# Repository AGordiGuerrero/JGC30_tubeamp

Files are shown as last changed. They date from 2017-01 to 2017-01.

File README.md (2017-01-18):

# JGC30_tubeamp

"Small" guitar tube amplifier with two preamp channels.

It is conceived to be inserted in a small combo box with a single 12" speaker. 

Author: @AGordiGuerrero
        @SolEpcc
        University of Extremadura. Spain.
        
Features:
 - Two preamp channels:
      - Channel 1: Vox AC30 Top Boost type
      - Channel 2: Marshall JCM800 type
  - Around 10-15W of output power

Revision history:
  - V0.3: preamp PCB design with Kicad. It includes a supposedly well defined BOM.

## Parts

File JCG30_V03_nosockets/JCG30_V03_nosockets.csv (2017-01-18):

Reference | Value | Footprint | Datasheet | Characteristics | Description | MFN | MFP | Package ID | Source1 | Source1Part | Source1Price | Source1Link | Notes | MFS
P1 | INPUT | Wire_Pads:SolderWirePad_single_1-5mmDrill
P19 | OUTPUT | Wire_Pads:SolderWirePad_single_1-5mmDrill
U2 | CH1/CH2_A | Socket_Strips:Socket_Strip_Straight_1x03 |  | 120VAC | 3PDT toggle switch, ON - NONE - ON | E-Switch | 1003P1T1B1M1QEH | Value | Mouser | 612-100-M1111 | 4,79 € | http://www.mouser.es/ProductDetail/E-Switch/1003P1T1B1M1QEH/ | Value
R1 | 1M | Resistors_THT:Resistor_Horizontal_RM10mm |  | 0.25W | Metal film through hole resistor | Vishay | CCF551M00FKE36 | MFR | Mouser | 71-CCF551M00FKE36 | 0.16€ | http://www.mouser.es/ProductDetail/Vishay/CCF551M00FKE36/ | Value | Value
C17 | 47u | Capacitors_THT:C_Radial_D14_L31.5_P5 |  | 450VDC | General Purpose Electrolytic Capacitors | Panasonic | EEU-EE2W470S | EE | Mouser | 667-EEU-EE2W470S | 2.32€ | http://www.mouser.es/ProductDetail/Panasonic/EEU-EE2W470S/?qs=sGAEpiMZZMtZ1n0r9vR22dN7zJS18SGVwev2rCc7kfs%3d | Value
R4 | 2k7 | Resistors_THT:Resistor_Horizontal_RM10mm |  | 0.25W | Metal film through hole resistor | Yageo | MFR-25FRF52-2K7 | MFR | Mouser | 603-MFR-25FRF52-2K7 | 0.113€ | http://www.mouser.es/ProductDetail/Yageo/MFR-25FRF52-2K7/ | Value
RV1 | 1MA | Potentiometers:Potentiometer_WirePads_Small |  | 60mW | Carbon potentiometer, rotatory, serrated | Alpha (Taiwan) | RV16AF-20-15K-A1M-3LA | Through hole, panel mount | Mouser | 313-1530F-1M | 1,62 € | http://www.mouser.es/ProductDetail/Alpha-Taiwan/RV16AF-20-15K-A1M-3LA/ | Value
R2 | 68k | Resistors_THT:Resistor_Horizontal_RM10mm |  | 0.25W | Metal film through hole resistor | Yageo | MFR-25FTE52-68K | MFR | Mouser | 603-MFR-25FTE52-68K | 0.113€ | http://www.mouser.es/ProductDetail/Yageo/MFR-25FTE52-68K/?qs=sGAEpiMZZMu61qfTUdNhG0IXHLFuiNndqkYkeLIi2jk%3d | Value
C2 | 680n | Capacitors_THT:C_Rect_L7_W4.5_P5 |  | 50 VDC | Metallized Polyester (PET) Capacitors PCM 5 mm | WIMA | MKS2B036801C00JA00 | MKS2 | Mouser | 505-MKS2B036801C00JA | 0.342€ | http://www.mouser.es/ProductDetail/WIMA/MKS2B036801C00JA00/?qs=sGAEpiMZZMv1cc3ydrPrF7l45uRd9dVhXD8p2Cb2qBg%3d | Value
U1 | BRIGHT | Socket_Strips:Socket_Strip_Straight_1x02 |  | 125VAC | Toggle switch, ON-OFF | Mountain Switch | 10TC605 | Bulk | Mouser | 10TC605 | 2.16 € | http://www.mouser.es/ProductDetail/Mountain-Switch/10TC605/ | Value
C9 | 22n | Capacitors_THT:C_Rect_L7_W3.5_P5 |  | 400VAC | Double Metallized Polypropylene Film | Kemet | PHE450MK5220JR05 | PHE450 | Mouser | 80-PHE450MK5220JR05 | 0.67€ | http://www.mouser.es/ProductDetail/Kemet/PHE450MK5220JR05/ | Value
C5 | 470p | Capacitors_THT:C_Rect_L10_W2.5_P7.5 |  | 400VAC | Metallized Polypropylene Film Capacitor DC and Pulse Applications | Kemet | R75QD0470DQ30J | R75 | Mouser | 80-R75QD0470DQ30J | 0.811€ | http://www.mouser.es/ProductDetail/Kemet/R75QD0470DQ30J/ | Value
R15 | 47k | Resistors_THT:Resistor_Horizontal_RM10mm |  | 0.5W, 700W | Metal film through hole resistor | KOA Speer | MF1/2DC4702F | MF | Mouser | 660-MF1/2DC4702F | 0.161€ | http://www.mouser.es/ProductDetail/KOA-Speer/MF1-2DC4702F/?qs=sGAEpiMZZMu61qfTUdNhG0RUkTLGOdTMbrAUdwu816A%3d | Value
U4 | CH1/CH2_B | Socket_Strips:Socket_Strip_Straight_1x02 |  | Value | Value | Value | Value | Value | Value | Value | Value | Value | Value
P2 | V2A_G | Wire_Pads:SolderWirePad_single_1-5mmDrill
P3 | V2A_K | Wire_Pads:SolderWirePad_single_1-5mmDrill
P4 | V2A_A | Wire_Pads:SolderWirePad_single_1-5mmDrill
P8 | V2B_G | Wire_Pads:SolderWirePad_single_1-5mmDrill
P9 | V2B_K | Wire_Pads:SolderWirePad_single_1-5mmDrill
P10 | V2B_A | Wire_Pads:SolderWirePad_single_1-5mmDrill
P5 | V1A_G | Wire_Pads:SolderWirePad_single_1-5mmDrill
P6 | V1A_K | Wire_Pads:SolderWirePad_single_1-5mmDrill
P7 | V1A_A | Wire_Pads:SolderWirePad_single_1-5mmDrill
P11 | V3A_G | Wire_Pads:SolderWirePad_single_1-5mmDrill
P12 | V3A_K | Wire_Pads:SolderWirePad_single_1-5mmDrill
P13 | V3A_A | Wire_Pads:SolderWirePad_single_1-5mmDrill
P14 | V3B_G | Wire_Pads:SolderWirePad_single_1-5mmDrill
P15 | V3B_K | Wire_Pads:SolderWirePad_single_1-5mmDrill
P16 | V3B_A | Wire_Pads:SolderWirePad_single_1-5mmDrill
P17 | VCC | Wire_Pads:SolderWirePad_single_1-5mmDrill
C3 | 22u | Capacitors_THT:C_Radial_D6.3_L11.2_P2.5 |  | 35VDC | Electrolitic Aluminium Radial Lead Type | Panasonic | ECA-1VM220B | M | Mouser | ECA-1VM220B | 0.16€ | http://www.mouser.es/ProductDetail/Panasonic/ECA-1VM220B/?qs=sGAEpiMZZMvwFf0viD3Y3ffldXPLozaytDH8DKgv7WI%3d | Value
P18 | GROUND | Wire_Pads:SolderWirePad_single_1-5mmDrill
R12 | 1M | Resistors_THT:Resistor_Horizontal_RM10mm |  | 0.25W | Metal film through hole resistor | Vishay | CCF551M00FKE36 | MFR | Mouser | 71-CCF551M00FKE36 | 0.16€ | http://www.mouser.es/ProductDetail/Vishay/CCF551M00FKE36/ | Value
R3 | 68k | Resistors_THT:Resistor_Horizontal_RM10mm |  | 0.25W | Metal film through hole resistor | Yageo | MFR-25FTE52-68K | MFR | Mouser | 603-MFR-25FTE52-68K | 0.113€ | http://www.mouser.es/ProductDetail/Yageo/MFR-25FTE52-68K/?qs=sGAEpiMZZMu61qfTUdNhG0IXHLFuiNndqkYkeLIi2jk%3d | Value
R5 | 100k | Resistors_THT:Resistor_Horizontal_RM10mm |  | 0.5W, 500V | Metal film through hole resistor | Vishay | CMF60100K00FKEB | CMFIndustrial | Mouser | 71-CMF60100K00FKEB | 0.556€ | http://www.mouser.es/ProductDetail/Vishay-Dale/CMF60100K00FKEB/ | Value
R6 | 820R | Resistors_THT:Resistor_Horizontal_RM10mm |  | 0.25W | Metal film through hole resistor | Yageo | MFR-25FBF52-820R | MFR | Mouser | 603-MFR-25FBF52-820R | 0.113€ | http://www.mouser.es/ProductDetail/Yageo/MFR-25FBF52-820R/ | Value
R13 | 820R | Resistors_THT:Resistor_Horizontal_RM10mm |  | 0.25W | Metal film through hole resistor | Yageo | MFR-25FBF52-820R | MFR | Mouser | 603-MFR-25FBF52-820R | 0.113€ | http://www.mouser.es/ProductDetail/Yageo/MFR-25FBF52-820R/ | Value
R10 | 100k | Resistors_THT:Resistor_Horizontal_RM10mm |  | 0.5W, 500V | Metal film through hole resistor | Vishay | CMF60100K00FKEB | CMFIndustrial | Mouser | 71-CMF60100K00FKEB | 0.556€ | http://www.mouser.es/ProductDetail/Vishay-Dale/CMF60100K00FKEB/ | Value
R16 | 100k | Resistors_THT:Resistor_Horizontal_RM10mm |  | 0.5W, 500V | Metal film through hole resistor | Vishay | CMF60100K00FKEB | CMFIndustrial | Mouser | 71-CMF60100K00FKEB | 0.556€ | http://www.mouser.es/ProductDetail/Vishay-Dale/CMF60100K00FKEB/ | Value
R7 | 220k | Resistors_THT:Resistor_Horizontal_RM10mm |  | 2W, 500V | Metal film through hole resistor | Yageo | FMP200JR-52-220K | FMP | Mouser | 603-FMP200JR-52-220K | 0.245€ | http://www.mouser.es/ProductDetail/Yageo/FMP200JR-52-220K/?qs=sGAEpiMZZMu61qfTUdNhGztMfEiwFKKT8tJfn5xrilY%3d | Value
R19 | 220k | Resistors_THT:Resistor_Horizontal_RM10mm |  | 2W, 500V | Metal film through hole resistor | Yageo | FMP200JR-52-220K | FMP | Mouser | 603-FMP200JR-52-220K | 0.245€ | http://www.mouser.es/ProductDetail/Yageo/FMP200JR-52-220K/?qs=sGAEpiMZZMu61qfTUdNhGztMfEiwFKKT8tJfn5xrilY%3d | Value
R14 | 47k | Resistors_THT:Resistor_Horizontal_RM10mm |  | 0.5W, 700W | Metal film through hole resistor | KOA Speer | MF1/2DC4702F | MF | Mouser | 660-MF1/2DC4702F | 0.161€ | http://www.mouser.es/ProductDetail/KOA-Speer/MF1-2DC4702F/?qs=sGAEpiMZZMu61qfTUdNhG0RUkTLGOdTMbrAUdwu816A%3d | Value
R8 | 470k | Resistors_THT:Resistor_Horizontal_RM10mm |  | 0.25W, 250V | Metal film through hole resistor | Yageo | MFR-25FRF52-470K | MFR | Mouser | 603-MFR-25FRF52-470K | 0.087€ | http://www.mouser.es/ProductDetail/Yageo/MFR-25FRF52-470K/?qs=sGAEpiMZZMu61qfTUdNhG0IXHLFuiNndCa9frJHvSy8%3d | Value
R11 | 470k | Resistors_THT:Resistor_Horizontal_RM10mm |  | 0.25W, 250V | Metal film through hole resistor | Yageo | MFR-25FRF52-470K | MFR | Mouser | 603-MFR-25FRF52-470K | 0.087€ | http://www.mouser.es/ProductDetail/Yageo/MFR-25FRF52-470K/?qs=sGAEpiMZZMu61qfTUdNhG0IXHLFuiNndCa9frJHvSy8%3d | Value
R17 | 33k | Resistors_THT:Resistor_Horizontal_RM10mm |  | 0.6W, 350V | Metal film through hole resistor | Yageo | 603-MF0207FTE52-33K | MF0 | Mouser | 603-MF0207FTE52-33K | 0.104€ | http://www.mouser.es/ProductDetail/Yageo/MF0207FTE52-33K/?qs=sGAEpiMZZMu61qfTUdNhG9FodMeJR7x9rJbMY0rijM4%3d | Value
R18 | 33R | Resistors_THT:Resistor_Horizontal_RM10mm |  | 2W, 500V | Metal film through hole resistor | Vishay | PR02000203309JR500 | 5073 | Mouser | 594-5083NW33R00J | 0.321€ | http://www.mouser.es/ProductDetail/Vishay-BC-Components/PR02000203309JR500/ | Value
R20 | 47R | Resistors_THT:Resistor_Horizontal_RM10mm |  | 2W, 500V | Metal film through hole resistor | Vishay | PR02000204709JR500 | 5073 | Mouser | 594-5083NW47R00J | 0.321€ | http://www.mouser.es/ProductDetail/Vishay-BC-Components/PR02000203309JR500/ | Value
R9 | 10k | Resistors_THT:Resistor_Horizontal_RM10mm |  | 0.25W | Metal film through hole resistor | Yageo | MFR-25FRF52-10K | MFR | Mouser | 603-MFR-25FRF52-10K | 0.094€ | http://www.mouser.es/ProductDetail/Yageo/MFR-25FRF52-10K/?qs=sGAEpiMZZMu61qfTUdNhGztMfEiwFKKTpKeEBKehEYg%3d | Value
C11 | 680n | Capacitors_THT:C_Rect_L7_W4.5_P5 |  | 50 VDC | Metallized Polyester (PET) Capacitors PCM 5 mm | WIMA | MKS2B036801C00JA00 | MKS2 | Mouser | 505-MKS2B036801C00JA | 0.342€ | http://www.mouser.es/ProductDetail/WIMA/MKS2B036801C00JA00/?qs=sGAEpiMZZMv1cc3ydrPrF7l45uRd9dVhXD8p2Cb2qBg%3d | Value
C8 | 22u | Capacitors_THT:C_Radial_D6.3_L11.2_P2.5 |  | 35VDC | Electrolitic Aluminium Radial Lead Type | Panasonic | ECA-1VM220B | M | Mouser | ECA-1VM220B | 0.16€ | http://www.mouser.es/ProductDetail/Panasonic/ECA-1VM220B/?qs=sGAEpiMZZMvwFf0viD3Y3ffldXPLozaytDH8DKgv7WI%3d | Value
C4 | 470p | Capacitors_THT:C_Rect_L7_W4.5_P5 |  | 63VAC | Metallized Polyester (PET) Capacitors PCM 5 mm | WIMA | FKP2D004701D00JSSD | FKP2 | Mouser | 505-FKP2470/100/5 | 0.352€ | http://www.mouser.es/ProductDetail/WIMA/FKP2D004701D00JSSD/ | Value
C10 | 470p | Capacitors_THT:C_Rect_L7_W4.5_P5 |  | 63VAC | Metallized Polyester (PET) Capacitors PCM 5 mm | WIMA | FKP2D004701D00JSSD | FKP2 | Mouser | 505-FKP2470/100/5 | 0.352€ | http://www.mouser.es/ProductDetail/WIMA/FKP2D004701D00JSSD/ | Value
C16 | 470p | Capacitors_THT:C_Rect_L10_W2.5_P7.5 |  | 400VAC | Metallized Polypropylene Film Capacitor DC and Pulse Applications | Kemet | R75QD0470DQ30J | R75 | Mouser | 80-R75QD0470DQ30J | 0.811€ | http://www.mouser.es/ProductDetail/Kemet/R75QD0470DQ30J/ | Value
C6 | 1n | Capacitors_THT:C_Rect_L7_W4.5_P5 |  | 63VAC | Polypropylene (PP) Capacitors | WIMA | FKS2D011001A00KC00 | FKP2 | Mouser | 505-FKS2D011001A00KC00 | 0.191€ | http://www.mouser.es/ProductDetail/WIMA/FKS2D011001A00KC00/?qs=sGAEpiMZZMv1cc3ydrPrF2CPLAojp4yWK6zCnEZkMTQ%3d | Value
C7 | 100p | Capacitors_THT:C_Rect_L7_W4.5_P5 |  | 63VAC | Polypropylene (PP) Capacitors | WIMA | FKS2D011001A00KC00 | FKP2 | Mouser | 505-FKP2D001001D00JO00 | 0.141€ | http://www.mouser.es/ProductDetail/WIMA/FKP2D001001D00JO00/?qs=sGAEpiMZZMv1cc3ydrPrF2CPLAojp4yW29gRXGnm4As%3d | Value
C13 | 22n | Capacitors_THT:C_Rect_L7_W3.5_P5 |  | 400VAC | Double Metallized Polypropylene Film | Kemet | PHE450MK5220JR05 | PHE450 | Mouser | 80-PHE450MK5220JR05 | 0.67€ | http://www.mouser.es/ProductDetail/Kemet/PHE450MK5220JR05/ | Value
C15 | 22n | Capacitors_THT:C_Rect_L7_W3.5_P5 |  | 400VAC | Double Metallized Polypropylene Film | Kemet | PHE450MK5220JR05 | PHE450 | Mouser | 80-PHE450MK5220JR05 | 0.67€ | http://www.mouser.es/ProductDetail/Kemet/PHE450MK5220JR05/ | Value
C14 | 22n | Capacitors_THT:C_Rect_L7_W3.5_P5 |  | 400VAC | Double Metallized Polypropylene Film | Kemet | PHE450MK5220JR05 | PHE450 | Mouser | 80-PHE450MK5220JR05 | 0.67€ | http://www.mouser.es/ProductDetail/Kemet/PHE450MK5220JR05/ | Value
C12 | 47n | Capacitors_THT:C_Rect_L7_W4.5_P5 |  | 400VAC | Metallized Polyester (PET) Capacitors PCM 5 mm | WIMA | MKS4J024702F00KSSD | MKS4 | Mouser | 505-MKS2B036801C00JA | 0.342€ | http://www.mouser.es/ProductDetail/WIMA/MKS4J024702F00KSSD/?qs=sGAEpiMZZMv1cc3ydrPrFwgzP98AO9id6x3yOoT7uvw%3d | Value
C18 | 47u | Capacitors_THT:C_Radial_D14_L31.5_P5 |  | 450VDC | General Purpose Electrolytic Capacitors | Panasonic | EEU-EE2W470S | EE | Mouser | 667-EEU-EE2W470S | 2.32€ | http://www.mouser.es/ProductDetail/Panasonic/EEU-EE2W470S/?qs=sGAEpiMZZMtZ1n0r9vR22dN7zJS18SGVwev2rCc7kfs%3d | Value
RV2 | 500k | Potentiometers:Potentiometer_WirePads_Small |  | 60mW | Carbon potentiometer, rotatory, serrated | Alpha (Taiwan) | RV16AF-20-15K-A500K-3LA | Through hole, panel mount | Mouser | 313-1530F-500K | 1,62 € | http://www.mouser.es/ProductDetail/Alpha-Taiwan/RV16AF-20-15K-A500K-3LA/ | Value
RV4 | 1MA | Potentiometers:Potentiometer_WirePads_Small |  | 60mW | Carbon potentiometer, rotatory, serrated | Alpha (Taiwan) | RV16AF-20-15S1-C1M-LA | Through hole, panel mount | Mouser | 313-1540F-1M | 1,62 € | http://www.mouser.es/ProductDetail/Alpha-Taiwan/RV16AF-20-15S1-C1M-LA/ | Value
RV5 | 25kB | Potentiometers:Potentiometer_WirePads_Small |  | 60mW | Carbon potentiometer, rotatory, round | Alpha (Taiwan) | RV16AF-10-15R1-B25K-LA | Solder lugs, panel mount | Mouser | 313-1000F-25K | 1,62 € | http://www.mouser.es/ProductDetail/Alpha-Taiwan/RV16AF-10-15R1-B25K-LA/ | Value
RV3 | 250kB | Potentiometers:Potentiometer_WirePads_Small |  | 125mW | Carbon potentiometer, rotatory, round | Alpha (Taiwan) | RV16AF-10-15R1-B250K-LA | Solder lugs, panel mount | Mouser | 313-1000F-250K | 1,62 € | http://www.mouser.es/ProductDetail/Alpha-Taiwan/RV16AF-10-15R1-B250K-LA/ | Value
U3 | VTG/MDN | Socket_Strips:Socket_Strip_Straight_1x02 |  | 125VAC | Toggle switch, ON-OFF | Mountain Switch | 10TC605 | Bulk | Mouser | 10TC605 | 2.16 € | http://www.mouser.es/ProductDetail/Mountain-Switch/10TC605/ | Value
C1 | 22n | Capacitors_THT:C_Rect_L7_W3.5_P5 |  | 400VAC | Double Metallized Polypropylene Film | Kemet | PHE450MK5220JR05 | PHE450 | Mouser | 80-PHE450MK5220JR05 | 0.67€ | http://www.mouser.es/ProductDetail/Kemet/PHE450MK5220JR05/ | Value

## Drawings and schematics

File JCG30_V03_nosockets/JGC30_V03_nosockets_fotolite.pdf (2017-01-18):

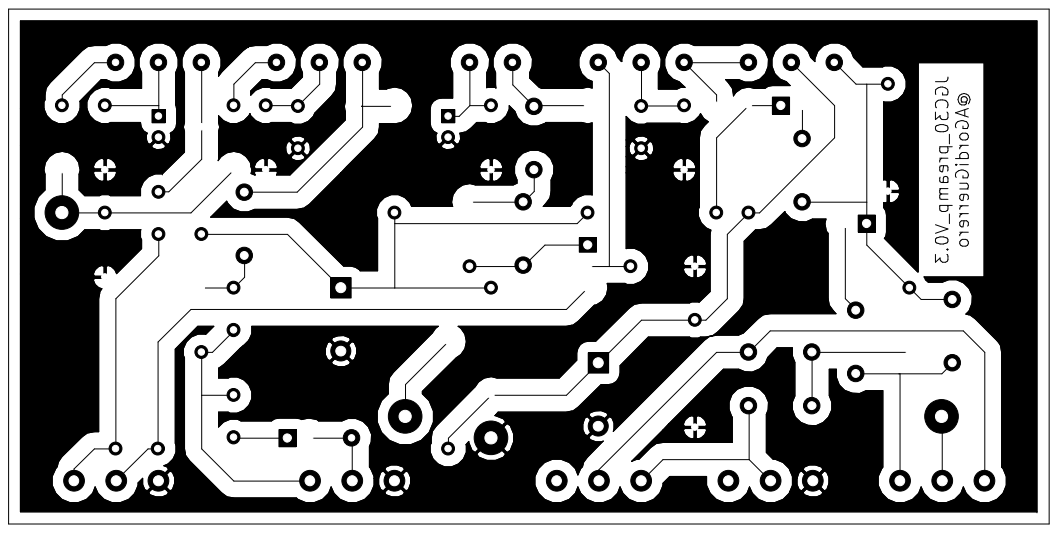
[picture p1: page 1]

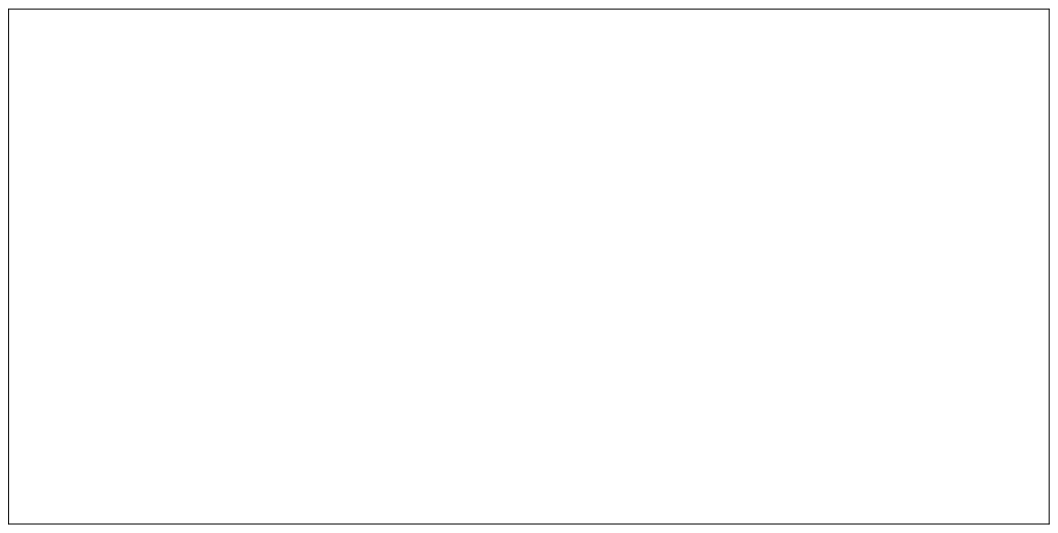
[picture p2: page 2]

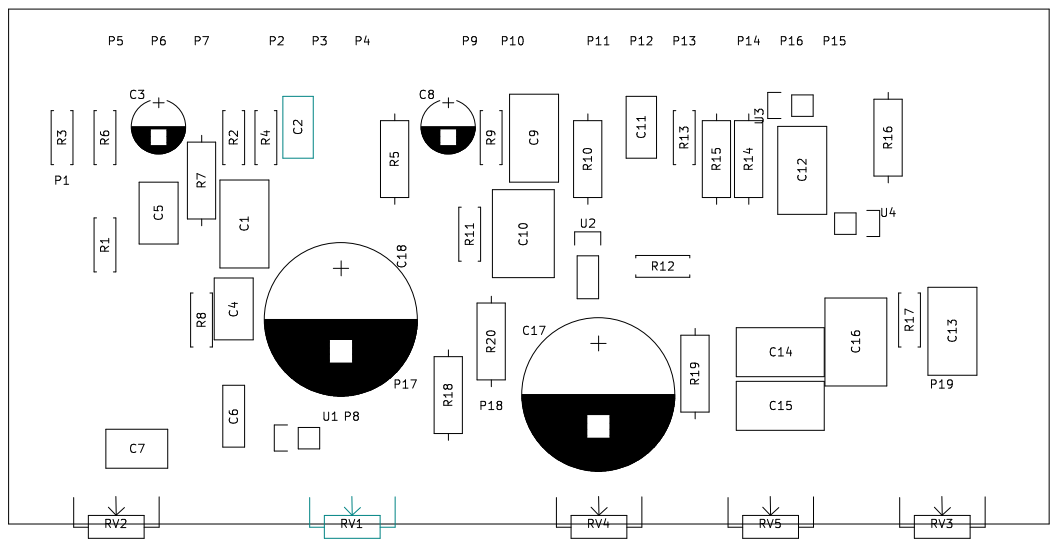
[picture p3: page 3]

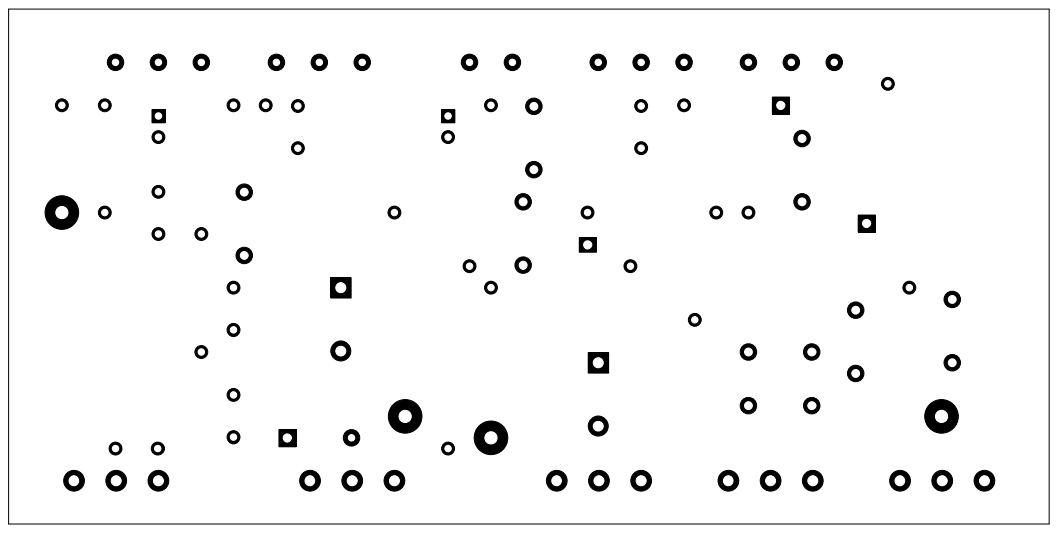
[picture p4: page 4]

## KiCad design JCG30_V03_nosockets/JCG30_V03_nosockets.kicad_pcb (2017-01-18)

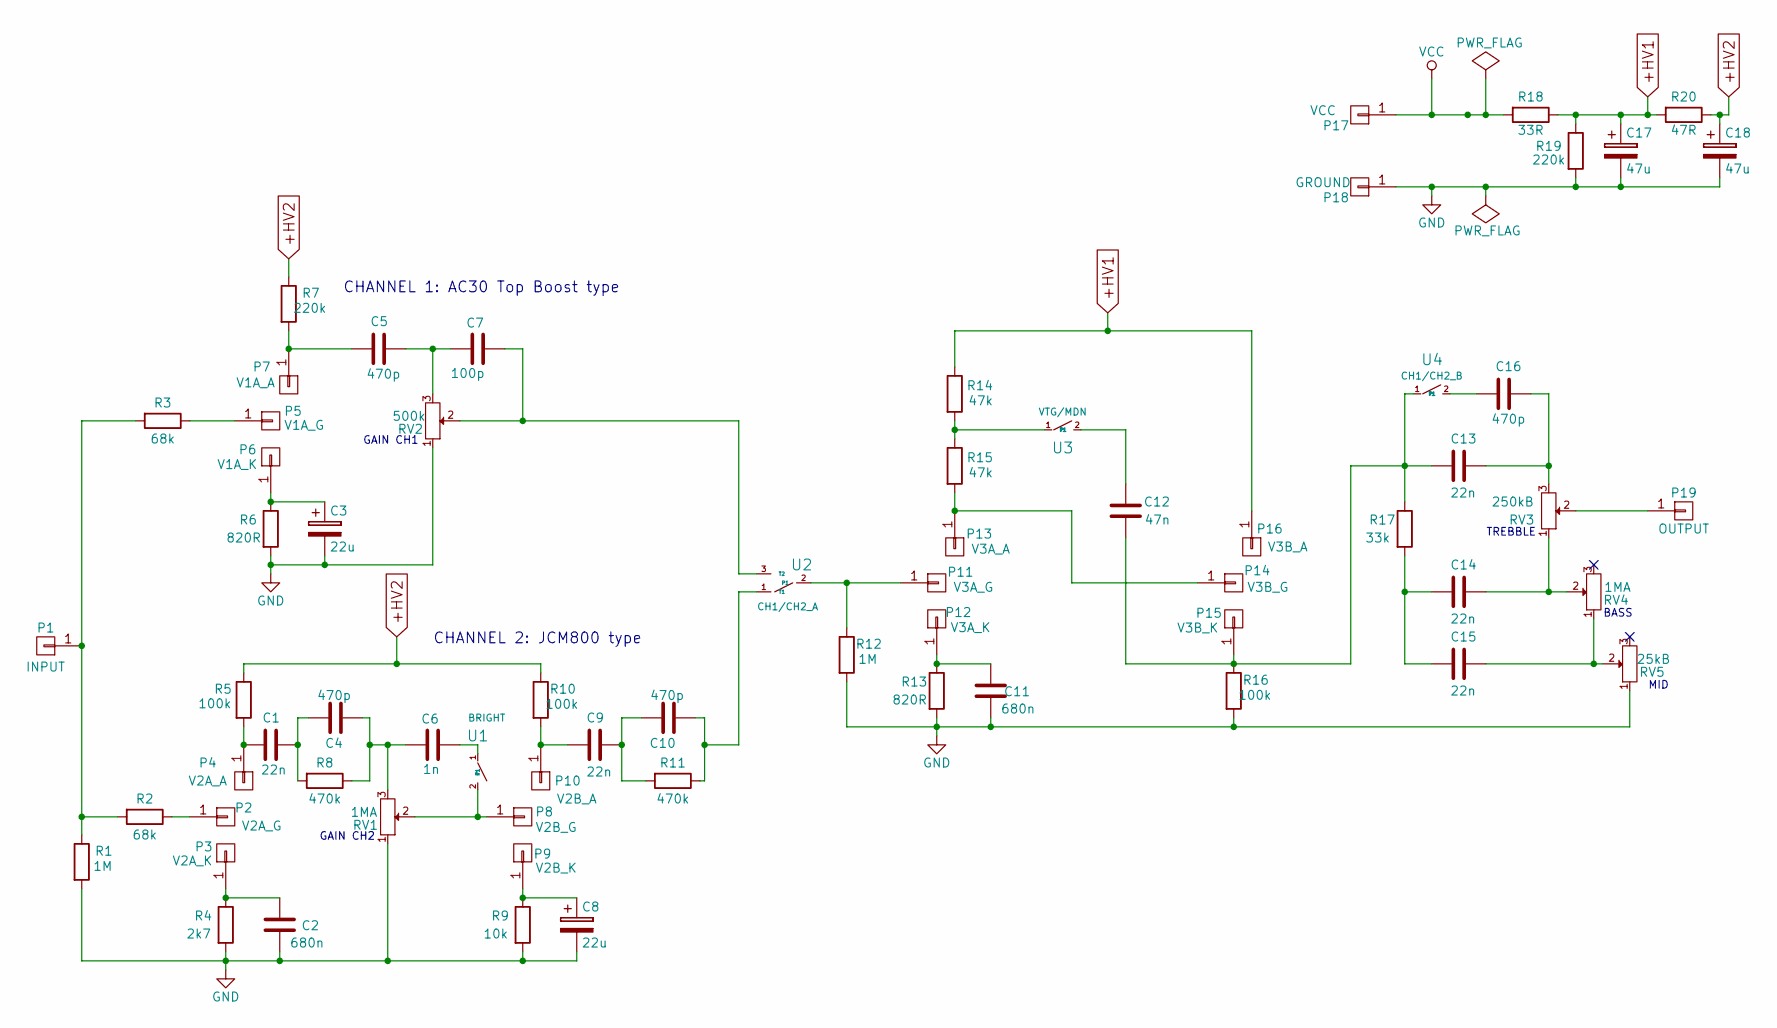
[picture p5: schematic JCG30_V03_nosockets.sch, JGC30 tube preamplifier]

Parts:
C1, C9, C13, C14, C15: 22n; C_Rect_L7_W3.5_P5
C2, C11: 680n; C_Rect_L7_W4.5_P5
C3, C8: 22u; C_Radial_D6.3_L11.2_P2.5
C4, C10: 470p; C_Rect_L7_W4.5_P5
C5, C16: 470p; C_Rect_L10_W2.5_P7.5
C6: 1n; C_Rect_L7_W4.5_P5
C7: 100p; C_Rect_L7_W4.5_P5
C12: 47n; C_Rect_L7_W4.5_P5
C17, C18: 47u; C_Radial_D14_L31.5_P5
P1: INPUT; SolderWirePad_single_1-5mmDrill
P2: V2A_G; SolderWirePad_single_1-5mmDrill
P3: V2A_K; SolderWirePad_single_1-5mmDrill
P4: V2A_A; SolderWirePad_single_1-5mmDrill
P5: V1A_G; SolderWirePad_single_1-5mmDrill
P6: V1A_K; SolderWirePad_single_1-5mmDrill
P7: V1A_A; SolderWirePad_single_1-5mmDrill
P8: V2B_G; SolderWirePad_single_1-5mmDrill
P9: V2B_K; SolderWirePad_single_1-5mmDrill
P10: V2B_A; SolderWirePad_single_1-5mmDrill
P11: V3A_G; SolderWirePad_single_1-5mmDrill
P12: V3A_K; SolderWirePad_single_1-5mmDrill
P13: V3A_A; SolderWirePad_single_1-5mmDrill
P14: V3B_G; SolderWirePad_single_1-5mmDrill
P15: V3B_K; SolderWirePad_single_1-5mmDrill
P16: V3B_A; SolderWirePad_single_1-5mmDrill
P17: VCC; SolderWirePad_single_1-5mmDrill
P18: GROUND; SolderWirePad_single_1-5mmDrill
P19: OUTPUT; SolderWirePad_single_1-5mmDrill
R1, R12: 1M; Resistor_Horizontal_RM10mm
R2, R3: 68k; Resistor_Horizontal_RM10mm
R4: 2k7; Resistor_Horizontal_RM10mm
R5, R10, R16: 100k; Resistor_Horizontal_RM10mm
R6, R13: 820R; Resistor_Horizontal_RM10mm
R7, R19: 220k; Resistor_Horizontal_RM10mm
R8, R11: 470k; Resistor_Horizontal_RM10mm
R9: 10k; Resistor_Horizontal_RM10mm
R14, R15: 47k; Resistor_Horizontal_RM10mm
R17: 33k; Resistor_Horizontal_RM10mm
R18: 33R; Resistor_Horizontal_RM10mm
R20: 47R; Resistor_Horizontal_RM10mm
RV1, RV4: 1MA; Potentiometer_WirePads_Small
RV2: 500k; Potentiometer_WirePads_Small
RV3: 250kB; Potentiometer_WirePads_Small
RV5: 25kB; Potentiometer_WirePads_Small
U1: BRIGHT; Socket_Strip_Straight_1x02
U2: CH1/CH2_A; Socket_Strip_Straight_1x03
U3: VTG/MDN; Socket_Strip_Straight_1x02
U4: CH1/CH2_B; Socket_Strip_Straight_1x02

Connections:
+HV1: C17.1, P16.1, R14.1, R18.1, R19.1, R20.2
+HV2: C18.1, R5.1, R7.1, R10.1, R20.1
GND: C2.1, C3.2, C8.2, C11.1, C17.2, C18.2, P18.1, R1.2, R4.2, R6.2, R9.2, R12.2, R13.2, R16.2, R19.2, RV1.1, RV2.1, RV5.1
unnamed: C1.1, C4.1, R8.2
unnamed: C1.2, P4.1, R5.2
unnamed: C2.2, P3.1, R4.1
unnamed: C3.1, P6.1, R6.1
unnamed: C4.2, C6.1, R8.1, RV1.3
unnamed: C5.1, C7.1, RV2.3
unnamed: C5.2, P7.1, R7.2
unnamed: C6.2, U1.1
unnamed: C7.2, RV2.2, U2.3 (T2)
unnamed: C8.1, P9.1, R9.1
unnamed: C9.2, P10.1, R10.2
unnamed: C9.1, C10.1, R11.2
unnamed: C10.2, R11.1, U2.1 (T1)
unnamed: C11.2, P12.1, R13.1
unnamed: C12.1, C13.2, P15.1, R16.1, R17.1, U4.1
unnamed: C12.2, U3.2 (T1)
unnamed: C13.1, C16.1, RV3.3
unnamed: C14.1, RV3.1, RV4.2
unnamed: C14.2, C15.2, R17.2
unnamed: C15.1, RV4.1, RV5.2
unnamed: C16.2, U4.2 (T1)
unnamed: P1.1, R1.1, R2.2, R3.2
unnamed: P2.1, R2.1
unnamed: P5.1, R3.1
unnamed: P8.1, RV1.2, U1.2 (T1)
unnamed: P11.1, R12.1, U2.2 (P1)
unnamed: P13.1, P14.1, R15.2
unnamed: P19.1, RV3.2
unnamed: R14.2, R15.1, U3.1
VCC: P17.1, R18.2

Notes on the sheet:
TREBBLE
BASS
MID
GAIN CH2
GAIN CH1
CHANNEL 1: AC30 Top Boost type
CHANNEL 2: JCM800 type

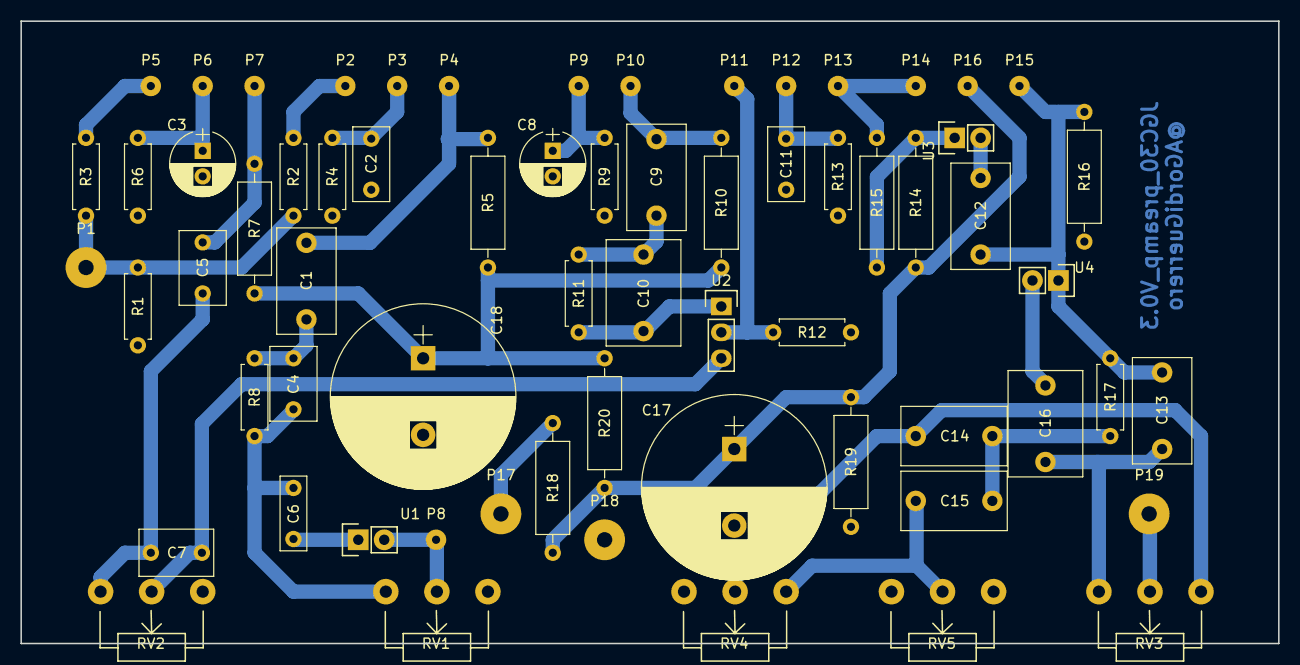
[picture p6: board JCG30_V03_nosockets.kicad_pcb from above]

Board: 2 copper layers, 123.2 x 61.0 mm, 66 parts (0 on the bottom side), 33 nets.
